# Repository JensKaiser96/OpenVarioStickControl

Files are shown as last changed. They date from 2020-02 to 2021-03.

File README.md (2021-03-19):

# Source Material

### [Orginal Projekt](https://www.openvario.org/doku.php?id=projects:remote_00:top)

### Komponenten
- PCB: 
  [Vorlage](https://github.com/adafruit/Adafruit_Atmega32u4_Breakout_Board)
 
- Buttons: \
  [RAFI 001.503 Kurzhubtaster, RACON 12, 42VAC/DC, SMD](https://www.reichelt.de/kurzhubtaster-racon-8-42vac-dc-smd-rafi-100-503-p110835.html)
  [Datenblatt](https://cdn-reichelt.de/documents/datenblatt/C200/DS_GER_RACON.pdf) \
  [Sollfahrt-Switch](https://www.reichelt.de/smd-kurzhubtaster-vert-montage-hoehe-5-0mm-taster-9315-p44514.html)
  
- [Joystick:  E-Switch JS5208](https://www.digikey.de/products/de?keywords=JS5208%20)

- [MicroController: ATMEGA32U4](https://www.digikey.de/product-detail/de/microchip-technology/ATMEGA32U4-AU/ATMEGA32U4-AU-ND/1914602)
  [Pin-mapping](https://www.arduino.cc/en/Hacking/PinMapping32u4)

- [Quarz: 7A-16.000MAAJ-T](https://www.digikey.de/product-detail/de/txc-corporation/7A-16.000MAAJ-T/887-1086-2-ND/2118770)
  
- [Sicherung: 04000025WR (500mA)](https://www.digikey.de/product-detail/de/04000025WR/F12131CT-ND/10271166)

### Sonstiges:
Bootloader: https://murchlabs.com/monday-experiment-bootloading-an-atmega32u4-with-arduino/

| Arduino Pin | Atmega 32u4 Pin |
|:---:|:---:|
| 10 | 13  |
| 11 | 10  |
| 12 | 11  |
| 13 | 9 |
| 5V | 5V  |
| GND | GND |

1. Connect Arduino Uno to Atmega 32u4 according to the above Table
2. Connect Arduino Uno via USB to Computer
3. Start Ardinio IDE
4. Arduino as ISP, Leonardo Bootloader

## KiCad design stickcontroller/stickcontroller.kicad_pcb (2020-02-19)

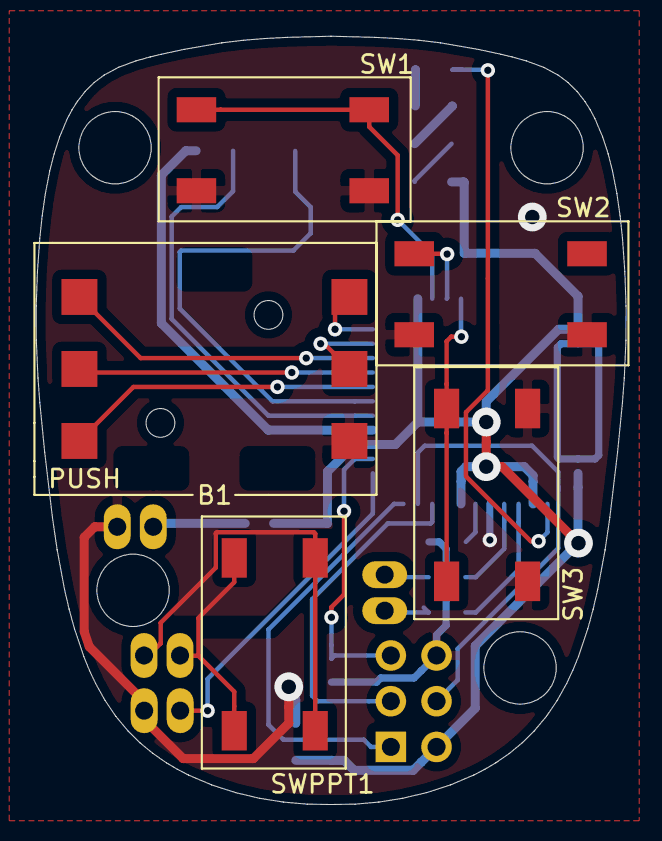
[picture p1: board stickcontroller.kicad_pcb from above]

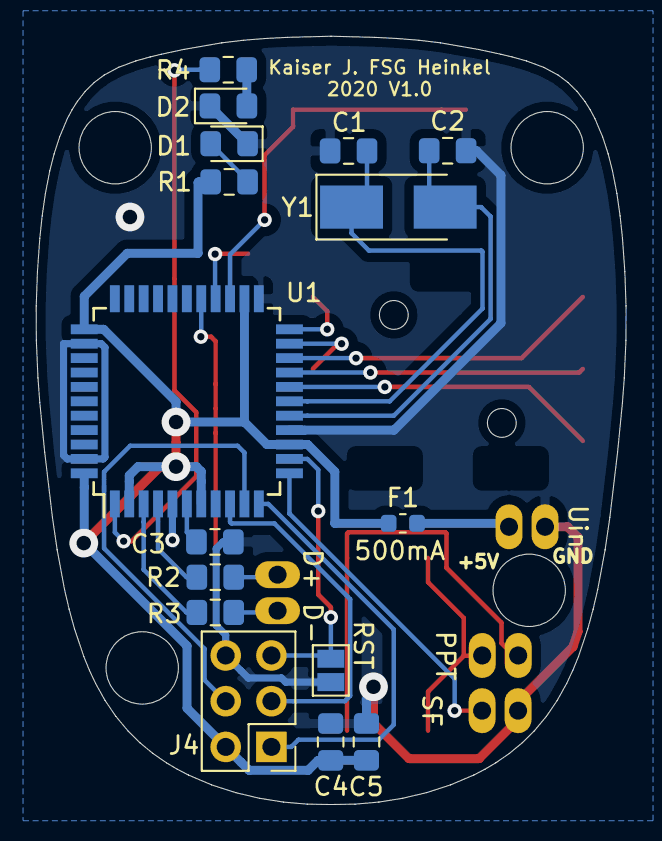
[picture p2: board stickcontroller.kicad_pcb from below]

Board: 2 copper layers, 32.8 x 42.7 mm, 25 parts (20 on the bottom side), 28 nets.

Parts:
B1: 4-direction-joystick; JS5208
C1, C2: 18pf; C_0805_2012Metric_Pad1.15x1.40mm_HandSolder
C3: 1uF; C_0805_2012Metric_Pad1.15x1.40mm_HandSolder
C4: 0.1uF; C_0805_2012Metric_Pad1.15x1.40mm_HandSolder
C5: 10uF; C_0805_2012Metric_Pad1.15x1.40mm_HandSolder
D1, D2: LED; LED_0805_2012Metric_Pad1.15x1.40mm_HandSolder
D+ D-: Conn_01x02; SolderWirePadOval_2
F1: 500mA; Fuse_0603_1608Metric
J4: Conn_02x03; PinHeader_2x03_P2.54mm_Vertical
PPT: Conn_01x02; SolderWirePadOval_2
R1, R4: 1K; R_0805_2012Metric_Pad1.15x1.40mm_HandSolder
R2, R3: 22; R_0805_2012Metric_Pad1.15x1.40mm_HandSolder
RST: Jumper_NO_Small; SolderJumper-2_P1.3mm_Open_Pad1.0x1.5mm
SF: Conn_01x02; SolderWirePadOval_2
SW1, SW2, SW3: SW_Push; Reichelt_RAFI_Kurzhubtaster
SWPPT1: SW_Push; Reichelt_RAFI_Kurzhubtaster
U1: ATmega32U4-AU; TQFP-44_10x10mm_P0.8mm
Uin: Conn_01x02; SolderWirePadOval_2
Y1: 16MHz; Crystal_SMD_5032-2Pin_5.0x3.2mm_HandSoldering

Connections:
+5V: C4.1, C5.1, F1.1, J4.2, R1.2, U1.2, U1.7, U1.14, U1.24, U1.34, U1.44
/D+: D+ D-.2, R2.2
/D-: D+ D-.1, R3.2
GND: B1.6, C1.2, C2.2, C3.2, C4.2, C5.2, D1.1, D2.1, J4.6, RST.1, SF.2, SW1.2, SW2.2, SW3.2, U1.5, U1.15, U1.23, U1.35, U1.43, Uin.1
unnamed: B1.1, U1.20
unnamed: B1.2, U1.19
unnamed: B1.3, U1.18
unnamed: B1.4, U1.22
unnamed: B1.5, U1.21
unnamed: C1.1, U1.17, Y1.1
unnamed: C2.1, U1.16, Y1.2
unnamed: C3.1, U1.6
unnamed: D1.2, R1.1
unnamed: D2.2, R4.1
unnamed: F1.2, Uin.2
unnamed: PPT.1, SWPPT1.2
unnamed: PPT.2, SWPPT1.1
unnamed: J4.1, U1.11
unnamed: J4.3, U1.9
unnamed: J4.4, U1.10
unnamed: J4.5, RST.2, U1.13
unnamed: SF.1, U1.12
unnamed: R2.1, U1.4
unnamed: R3.1, U1.3
unnamed: R4.2, U1.1
unnamed: SW1.1, U1.25
unnamed: SW2.1, U1.26
unnamed: SW3.1, U1.27

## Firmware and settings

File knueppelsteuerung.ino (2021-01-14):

/*
  Code by Jens Kaiser 10.2020

  Button position:
   ___________
  / [1]       \      1 - Button 1
 |             |     
 |   ^     [2] |     2 - Button 2
 | <[J]>       |     J - Joystick (UP,DOWN,LEFT,RIGHT,PUSH)
 |   v         |     
 |         [3] |     3 - Button 3
 \  4          /
  \ '' [P]    /      P - Push to Talk (PPT) Button
   \_________/       4 - Contact Points for Vario Setting (Sollfahrt)

*/
#include <Keyboard.h>
#include <Mouse.h>
#define ARRAY_SIZE(array) (sizeof(array) / sizeof(array[0]))

// switching between mouse and arrowkeys
bool mousemode = false;
// switching between v and s
bool speedmode = false;
int mouse_dist = 1;

const unsigned int short_press = 20; // milliseconds a button has to be pressed to count as pressed
const unsigned int long_press = 500; // milliseconds a button has to be pressed to count as a long press
const unsigned int pause_max = 300; // max pause between key presses if continious
const unsigned int pause_min = 50; // min pause between key presses if continious
unsigned int pause = pause_max; // current pause setting
const byte pause_d = 20; // by how many millis the pause gets reduced each key send


void pressKey(byte key){
  Keyboard.press(key);
  delay(10);
  Keyboard.release(key);
  Serial.println(key);
}


class input {
  public:
    input(byte _pin, void (*s)(), void (*l)()){
      pin = _pin;
      action_short = s;
      action_long = l;
      action_cont = []() -> void {};
    }

    input(byte _pin, void (*c)()){
      pin = _pin;
      action_short = []() -> void {};
      action_long = []() -> void {};
      action_cont = c;
    }

    byte btn_time(){
      unsigned int count = millis() - count_edge;
      if(count < short_press) return 0;
      if(count < long_press) return 1;
      return 2;
    }
    
    byte pin; // physical pin connecting input to controller
    bool previous = 1; // saving previous input state for edge detection
    bool valid_press = false; // is the current state fits a valid button press
    bool key_send = false; // has a key press been send
    unsigned long count_edge = 0; // time of edge
    unsigned long count_key = 0; // time of key send
    void (*action_short)(){}; // function called on short press
    void (*action_long)(){};  // function called on long press
    void (*action_cont)(){};  // function called on continious press (holding the button down)
};

// declaring inputs
// buttons
// input function needs (PIN, Fuction for short button press, Function for long button press)
input Btn1 = input(4,  []() -> void {pressKey(KEY_F2);},          []() -> void {pressKey(KEY_F3);});
input Btn2 = input(12, []() -> void {pressKey(KEY_F1);},          []() -> void {pressKey('M');});
input Btn3 = input(6,  []() -> void {pressKey(KEY_ESC);},         []() -> void {pressKey('Q');});
input SF   = input(11,  []() -> void {speedmode ? pressKey('S') : pressKey('V');
                                     speedmode = not speedmode;}, []() -> void {});           
// joystick
input UP    = input(0,   []() -> void {mousemode ? Mouse.move(0, -mouse_dist) : pressKey(KEY_UP_ARROW);});
input DOWN  = input(3,   []() -> void {mousemode ? Mouse.move(0, mouse_dist)  : pressKey(KEY_DOWN_ARROW);});
input LEFT  = input(2,   []() -> void {mousemode ? Mouse.move(-mouse_dist, 0) : pressKey(KEY_LEFT_ARROW);});
input RIGHT = input(1,   []() -> void {mousemode ? Mouse.move(mouse_dist, 0)  : pressKey(KEY_RIGHT_ARROW);});
input PUSH  = input(30,  []() -> void {pressKey(KEY_RETURN);},  []() -> void {mousemode = not mousemode;});
// array pointing to all inputs
input* inputs[] = {&Btn1, &Btn2, &Btn3, &SF, &UP, &DOWN, &LEFT, &RIGHT, &PUSH};
int numinputs = 9;

void setup() {
  delay(1000);
  Serial.begin(9600);
  delay(1000);
  
  // pinMode setup
  for(int i=0; i < numinputs; i++){
    pinMode(inputs[i]->pin, INPUT_PULLUP);
  }

  Keyboard.begin();
}


void loop() {
  // iterate over all inputs
  for(int i = 0; i < numinputs; i++){
    bool state = not digitalRead(inputs[i]->pin);
    
    // detect falling edge
    if(inputs[i]->previous and not state){
      inputs[i]->count_edge = millis();
      Serial.println("Edge detected: " + String(inputs[i]->pin));
      inputs[i]->valid_press = false;
      pause = pause_max;
    }
    
    // detect valid button press 
    if(not state and inputs[i]->btn_time() == 1){
      inputs[i]->valid_press = true;
      inputs[i]->key_send = false;
    }
    
    // detect short, long and continous press
    if(inputs[i]->valid_press){
      // short press: detect rising edge before 500ms
      if(state and not inputs[i]->key_send){
        inputs[i]->action_short();
        inputs[i]->key_send = true;
      }
      // long press: no rising edge after 500ms
      if(inputs[i]->btn_time() == 2 and not inputs[i]->key_send){
        inputs[i]->action_long();
        inputs[i]->key_send = true;
      }
      // continious press: no rising edge ever
      if(not state and millis() - inputs[i]->count_key > pause){
        inputs[i]->action_cont();
        inputs[i]->count_key = millis();
        Serial.println(pause);
        pause = max(pause-pause_d, pause_min);
      }
    }
    
    
    // update previous
    inputs[i]->previous = state;
  }
}
